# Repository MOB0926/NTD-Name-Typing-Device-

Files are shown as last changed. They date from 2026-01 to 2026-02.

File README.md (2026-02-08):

# NTD-Name-Typing-Device
 
This is my attempt at this project. I set out to get my hands on FREE components but then quickly realized this was no easy task. At first I stuck to the templete, but it got boring (quckly). I then put my brain to work and came to the briliant idea of a macropad that types my name. And so the NTD-V1 (Name-Typing-Device) was born.

# PCB
 
I mostly followed the guide for this but restarted it a few times as my own Ideas came into play.
 
I have an interest studying EE so I really tried to learn from this part. I found it was actually pretty fun, specially when creating the PCB and figuring out the puzzle of connecting the components.
 
I used KICAD as the guide instructed (Though I am new to it so it took quite a while)
 
I first built the guide board to figure it out. With what I learned, and some playing around (And a LOT of google) I slowly came up with my personal design incorporating the XIAO-RP2040, 6 switches, an OLED, and two LEDs (That I kinda forgot to remove so they are now official).
    
imagen
    
imagen

# CAD
 
The guide called for Fusion 360 but im on a low power laptop and have more experience in Onshape, so I designed my Case there.
 
I started with the bottom and designed it with the dimesnions of my pcb and added a hole for the usb-c where I designed it to be.
   
imagen
   
After the bottom was completed I designed the top with the key switch layout holes and holes for the Oled and LEDs. I also added some text and made sure the screw holes lined up properlly.
   
imagen
   
Edit - 1/7/26

I realized a few days later that ther was a mesage on my project asking for a 3d render of my project. 

At the time I was traveling so I could not edit but now that I can I realized that the case was ALL WRONG so I changed a few dimensions and now it works.
     
*Case Top
     

     
*Case Bottom
     

    
*3D Render
    

   
*3D Render with components (No Keycaps B/C I could only find stl files and they ruined the vibe + I put a lot of work into finding key switches and placing them)
   

       
# Firmware
 
For programing im mostly clueless, so I had a lot of help from Chat GPT. I honestly have no clue if this works untill it works or spits out a lot of errors.
 
The srcipt is in python, and will be used with CircuitPython and kmk to power the board.
 
Features:
- Inputs from the key switches
- Oled display - welcome message ("Welcome to NTD")
 
So far this will make it work but there is a lot of room for improvement once I am able to put some actual effort into the code.
  
# Final Build



# Design Flaws

As per every design there are flaws.
- Only types my name
- LED wrong footprint (Still works though)
- Case design in general
    - LED holes in wrong location
    - Inproper space for key-caps to fully go down and grab on
    - USB slot way to short (So the case is not fully screwed down to acomodate)
- No PCB mounting holes (Its fine but would be nicer)

# BOM
 
Required Materials:
- Seeed XIAO RP2040 
- MX-Style switches (x6)
- 0.91 inch OLED display
- Blank DSA keycaps (x6)
- SK6812 MINI-E LEDs (x2)
- M3x8mm screws (x4)
- M3x5mx4mm heatset inserts (x4)
- 3D Printed Case

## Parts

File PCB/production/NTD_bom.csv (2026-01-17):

Designator | Footprint | Quantity | Value | LCSC Part #
D1, D2 | LED_SK6812MINI_PLCC4_3.5x3.5mm_P1.75mm | 2 | SK6812MINI
J1 | SSD1306-0.91-OLED-4pin-128x32 | 1 | Conn_01x04
SW1, SW2, SW3, SW4, SW5, SW6 | SW_Cherry_MX_1.00u_PCB | 6 | SW_Push
U1 | XIAO-RP2040-DIP | 1 | XIAO-RP2040-DIP

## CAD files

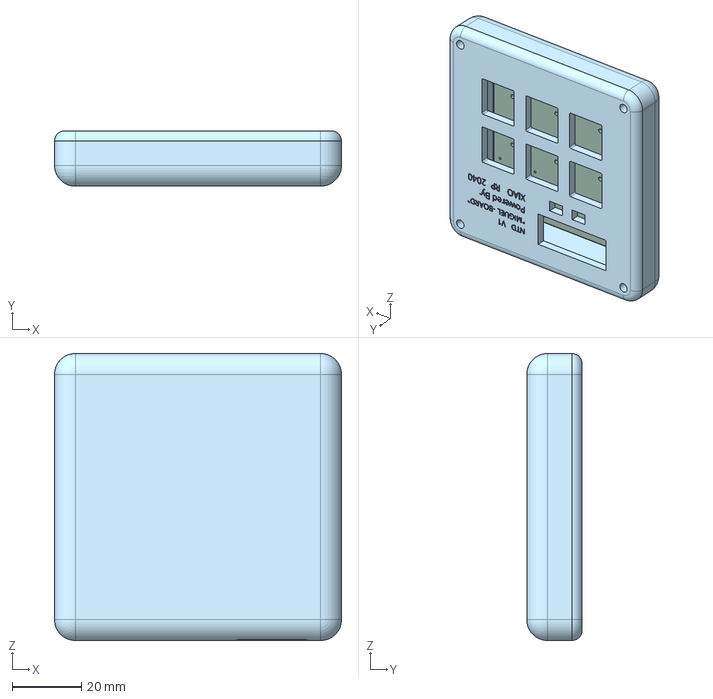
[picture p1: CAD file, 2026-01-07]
CAD/NTD-3D-Render.step
82.8 x 16.0 x 82.8 mm
NTD_PCB

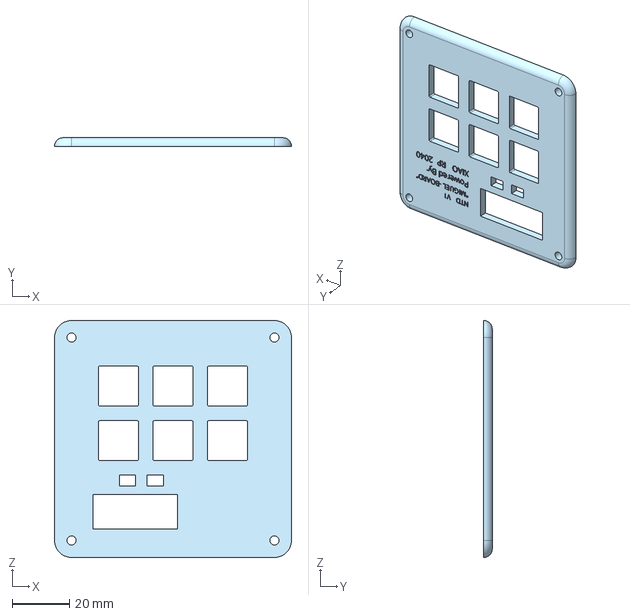
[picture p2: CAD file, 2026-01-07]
CAD/NTD-Case-Top.step
82.8 x 3.00 x 82.8 mm

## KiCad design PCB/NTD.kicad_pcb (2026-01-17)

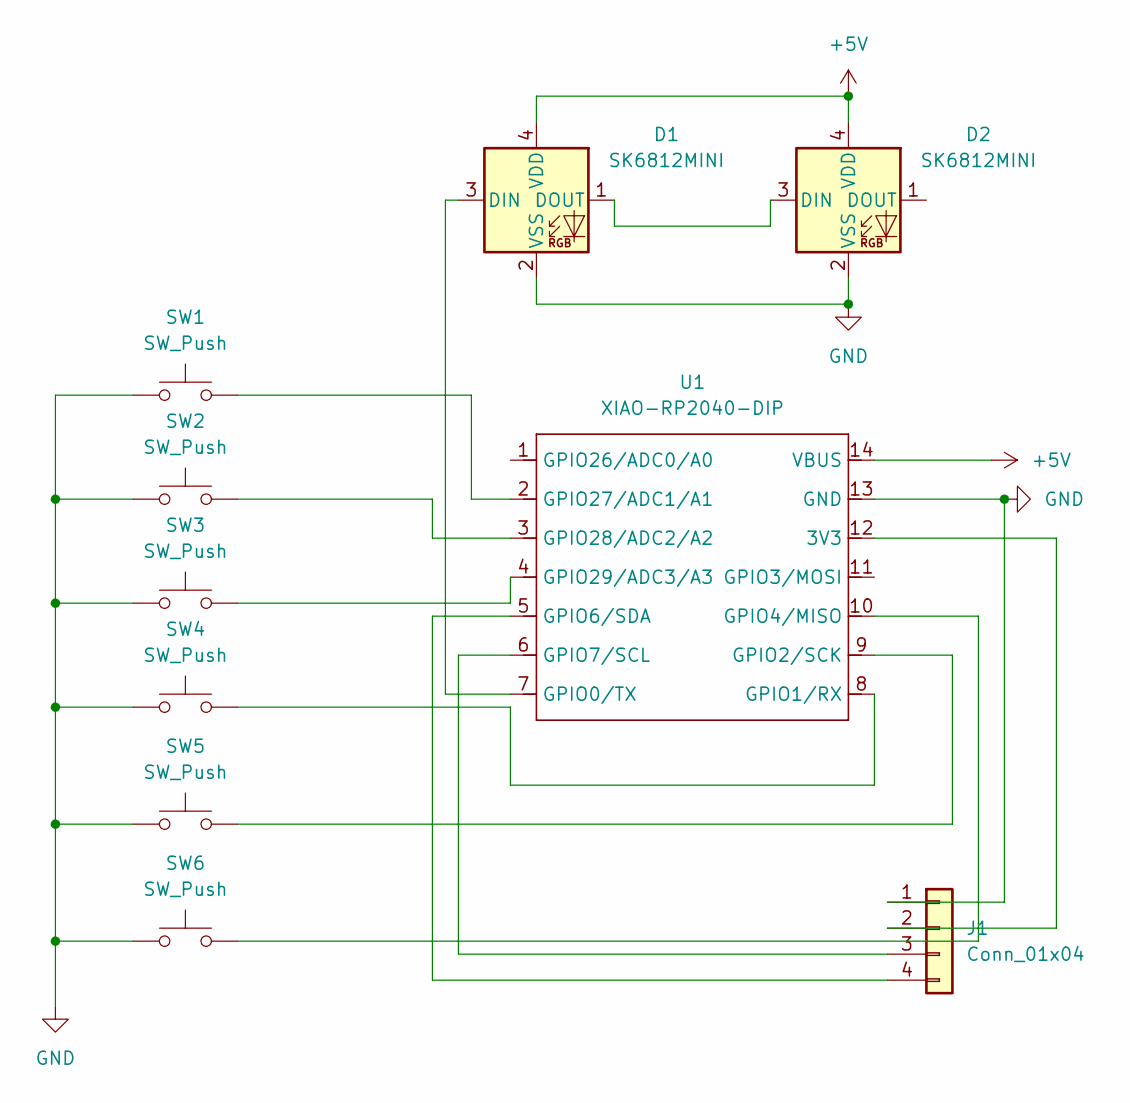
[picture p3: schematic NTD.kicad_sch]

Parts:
D1, D2: SK6812MINI; LED_SK6812MINI_PLCC4_3.5x3.5mm_P1.75mm
J1: Conn_01x04; SSD1306-0.91-OLED-4pin-128x32
SW1, SW2, SW3, SW4, SW5, SW6: SW_Push; SW_Cherry_MX_1.00u_PCB
U1: XIAO-RP2040-DIP

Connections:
+5V: D1.4 (VDD), D2.4 (VDD), U1.14 (VBUS)
GND: D1.2 (VSS), D2.2 (VSS), J1.1, SW1.1, SW2.1, SW3.1, SW4.1, SW5.1, SW6.1, U1.13 (GND)
unnamed: D1.3 (DIN), U1.7 (GPIO0/TX)
unnamed: D1.1 (DOUT), D2.3 (DIN)
unnamed: J1.2, U1.12 (3V3)
unnamed: J1.3, U1.6 (GPIO7/SCL)
unnamed: J1.4, U1.5 (GPIO6/SDA)
unnamed: SW4.2, U1.8 (GPIO1/RX)
unnamed: SW5.2, U1.9 (GPIO2/SCK)
unnamed: SW6.2, U1.10 (GPIO4/MISO)
unnamed: SW1.2, U1.2 (GPIO27/ADC1/A1)
unnamed: SW2.2, U1.3 (GPIO28/ADC2/A2)
unnamed: SW3.2, U1.4 (GPIO29/ADC3/A3)

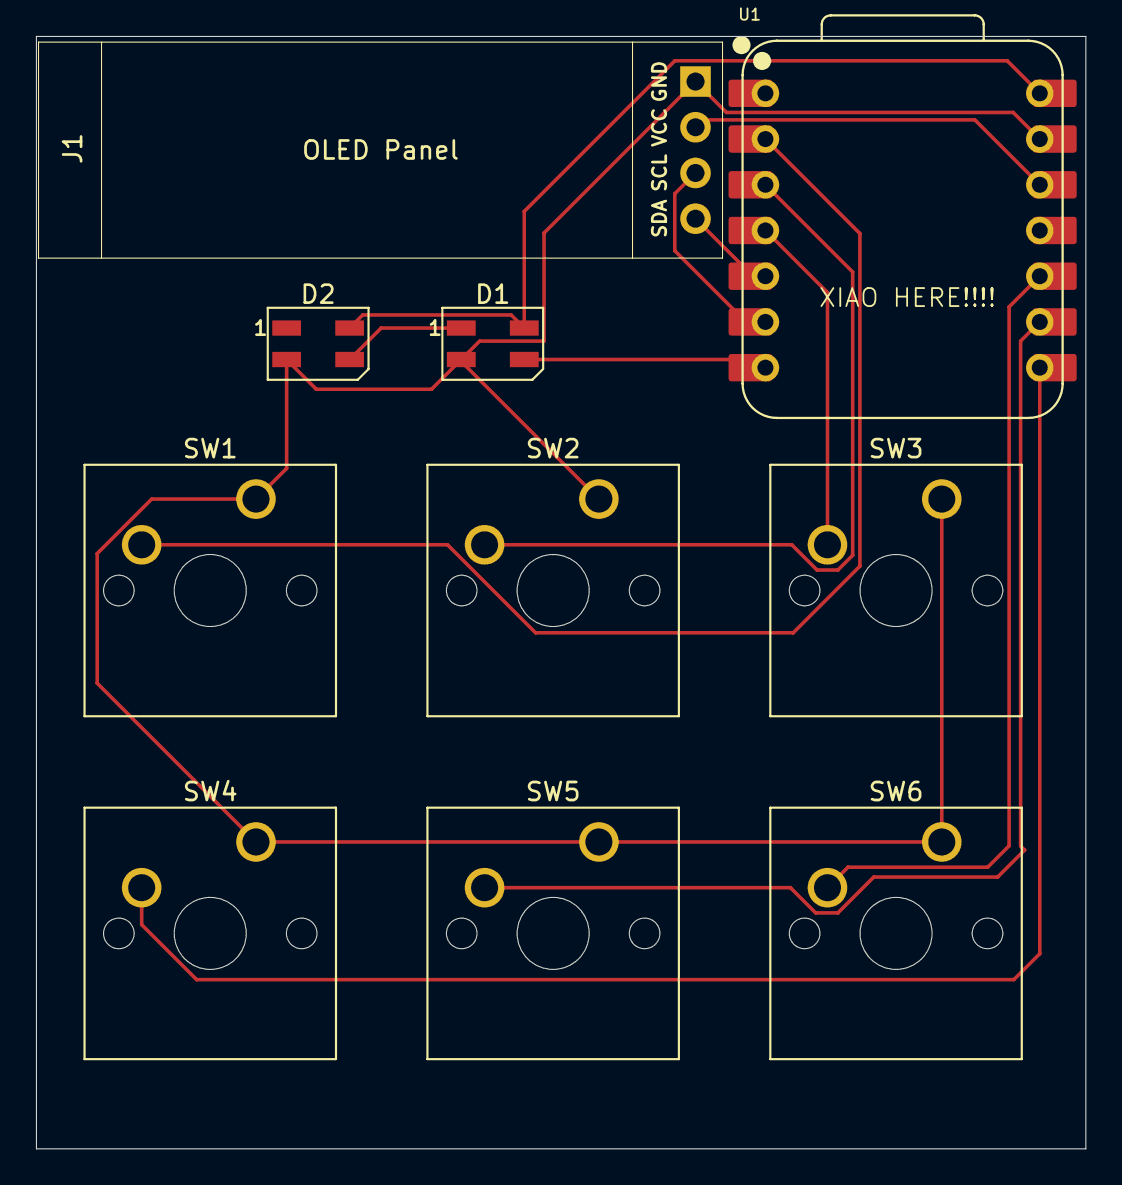
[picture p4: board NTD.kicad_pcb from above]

Board: 2 copper layers, 58.3 x 61.8 mm, 10 parts (0 on the bottom side), 13 nets.

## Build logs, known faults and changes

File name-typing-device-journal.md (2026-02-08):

<!--
  This journal is auto generated by Hack Club Blueprint.
-->

# 1/16/2026 - Tested Componets / Code  

_Time spent: 8.0h_  

I received my kit on 1/15. Since i have gotten my pins soldered and I set up on a breadboard to test. All works correctly except the OLED which is not ok either or both due to shipping / user error, so that will be scrapped for now. I (With a lot of ChatGPT) got the code working and tested it so now im ready to order my PCB and print out my case.



# 1/17/2026 - Ordered PCB  

_Time spent: 2.0h_  

I ordered my PCB (As of last night) It should arrive in 1-1.5 weeks which does not give me much time for build review but I think it will all be done except for the OLED.

One thing I noticed is that my LED footprint is wrong, but since I plan on raising them according to my case height then it should be fine as long as I get the pin order right.



# 1/22/2026 - Waiting :(  

_Time spent: 0.1h_  

The PCB as of a few days ago finished production, and is now on a flight towards its destination. I still wont receive this until next week probably so still I wait. 

I have the case files ready to get sliced and printed but that will have to wait until Saturday where I can print it at my robotics meet.



# 1/25/2026 - Case Printed  

_Time spent: 2.0h_  

I have finished printing my case. I was able to use one of my robotics team’s A1s.

I a noob messed up one of the heated inserts since I do not have a heated invert tool but hopefully I my school has one that I will be able to use. Additionally the bolts are a little long so I’ll see if I can get some shorter ones or maybe cut these down. 
(No I’m not stealing it. Part of my school’s STEAM / Robotics club (which I’m VP of) is that we are allowed to use school resources for projects)

I have everything ready except for the PCB which as of a few days ago arrived in NY so it should be here this week.



# 2/7/2026 - Done!!!!!!!!!!!!!!!!!!!!!!!!!!  

_Time spent: 8.0h_  

**Soldering**

I revived the PCB this week and got to work soldering the components onto it.

All went well except for the LEDs which had the wrong footprint, but it was an easy fix by just rotating them 90 degrees and very sketchy soldering.

NTD_PCB

**Final Build**

After the PCB was soldered I put it in the case and screwed it together. After that I added the key caps and the USB cable to try it out.



**Code**

The code works as of last time I played with it, but today I decided to play around with the OLED code to see if it would work. Last time I thought the OLED was broken but today troubleshooting my second attempt with ChatGPT to get the display to work I discovered my font file had to be in the root of the board not the LIB folder so it ALL works now. (YAYYYYY)

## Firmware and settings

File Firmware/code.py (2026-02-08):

import board
import neopixel
import busio
import displayio
import terminalio
from adafruit_display_text import label
import adafruit_displayio_ssd1306

from kmk.kmk_keyboard import KMKKeyboard
from kmk.scanners.keypad import KeysScanner
from kmk.keys import KC

# ---------------- Keyboard ----------------
keyboard = KMKKeyboard()

# ---------------- Keys ----------------
PINS = (
    board.D1,  # M
    board.D2,  # I
    board.D3,  # G
    board.D7,  # U
    board.D8,  # E
    board.D9,  # L
)

keyboard.matrix = KeysScanner(
    pins=PINS,
    value_when_pressed=False,
)

keyboard.keymap = [[
    KC.M,
    KC.I,
    KC.G,
    KC.U,
    KC.E,
    KC.L,
]]

# ---------------- LEDs ----------------
pixels = neopixel.NeoPixel(
    board.D6,
    2,
    brightness=0.3,
    auto_write=False
)

# Power LED
pixels[0] = (0, 255, 0)
pixels.show()

def after_key_handler(keyboard, key, is_pressed, *args):
    if is_pressed:
        pixels[1] = (0, 0, 255)
        pixels.show()

keyboard.after_key_press_handler = after_key_handler

# ---------------- OLED (SSD1306) ----------------
# Release any previously configured displays
displayio.release_displays()

# I2C pins: SDA=D4, SCL=D5
i2c = busio.I2C(board.D5, board.D4)

# 0.91" common OLED size (change to 64 if your module is 128x64)
WIDTH = 128
HEIGHT = 32

display = None
try:
    # Prefer displayio-backed driver (CircuitPython modern approach)
    display_bus = displayio.I2CDisplay(i2c, device_address=0x3C)
    # Rotate display 180 degrees to correct upside-down mounting
    display = adafruit_displayio_ssd1306.SSD1306(
        display_bus, width=WIDTH, height=HEIGHT, rotation=180
    )

    g = displayio.Group()
    text = "Welcome To NTD"
    text_area = label.Label(terminalio.FONT, text=text, color=0xFFFFFF)
    # Position roughly centered
    text_area.x = 2
    text_area.y = HEIGHT // 2
    g.append(text_area)
    display.show(g)
except AttributeError:
    # Older builds may not expose displayio.I2CDisplay — fall back to legacy driver
    try:
        import adafruit_ssd1306

        disp = adafruit_ssd1306.SSD1306_I2C(WIDTH, HEIGHT, i2c, addr=0x3C)
        # Try common rotation/flip options on legacy driver
        try:
            disp.rotation = 2
        except Exception:
            try:
                disp.rotate(2)
            except Exception:
                try:
                    disp.rotation = 180
                except Exception:
                    pass
        disp.fill(0)
        try:
            disp.text("Welcome To NTD", 0, HEIGHT // 2, 1)
        except Exception:
            # If text() isn't available, skip drawing text
            pass
        disp.show()
    except Exception:
        # If all display methods fail, leave display as None
        display = None

# ---------------- Start ----------------
if __name__ == "__main__":
    keyboard.go()
    

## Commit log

2025-12-08 Create Create PCB + Schematic
2025-12-08 Rename Create PCB + Schematic to PCB + Schematic
2025-12-27 Create Case-Top
2025-12-27 Update print statement from 'Hello' to 'Goodbye'
    [NTD.kicad_pcb]
2025-12-28 Enhance README with design process and images
    Expanded the README to include details about the PCB design process, CAD software used, and images of the designs.
2026-01-07 New CAD
    [NTD-3D-Render.step, NTD-Case-Top.step]
2026-01-07 Revise README with case updates and new images
    Updated the README to reflect changes made to the case dimensions and added images for the case top, bottom, and 3D render.
2026-01-07 Fix case dimensions and update 3D render images
    Corrected dimensions in the project case and updated images.
2026-01-08 Revise images and dimensions in README.md
    Updated image dimensions and added new images for case top, bottom, and 3D render sections in the README.
2026-01-08 Enhance 3D Render description in README
    Updated the 3D Render section with additional details about components and key switches.
